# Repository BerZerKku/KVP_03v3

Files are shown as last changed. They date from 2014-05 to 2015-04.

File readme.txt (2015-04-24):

Плата KVP_03v3.
Сделана в OrCAD 16.6.

Предназначена для использования в ОПТИКЕ и АВАНТах К400, РЗСК, Р400М 
сделанными в новом варианте.
Используется совместно с BVP не ранее 04v2, если не нужна цифровая
ретрансляция. И не ранее 04v3 если нужна.

Изменения:
Переделана цивровая ретрансляция. Сделан чистый 422 интерфейс и добавлен
сигнал управления.
Терминаторы 120 и 51Ом изменены на 240Ом.

Основной вариант (Р400М):
отсутствуют: цифровая ретрансляция, выходы ком.ПРД/ПРМ, вход ПУСК.

Вариант Р400:
добавлен выход "Предупреждение"

Вариант К400 (РЗСК):
плата запаивается полностью.

Недостатки:
Резисторы подтяжки стоят на выводах X/Y, что при переключении на 422 убирает
подтяжки с выводов A/B и оставляет вход 422 интерфейса без подтяжки. 
Вообще дуплекс/полудуплекс сделан хреново.
Место резисторов можно поставить предохранители.

!!!
На данный момент входы управления запаиваются только под 24.
Номиналы резисторов для других напряжений см. в РЭ.
!!!

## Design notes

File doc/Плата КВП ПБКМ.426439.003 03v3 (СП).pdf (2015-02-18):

№ | Наименование | Корпус | Кол. | Поз. | Примечание
| | | | | ПБКМ.426439.003

0

Изм | Лист | № докум. | Подп. | Дата
Разраб. | Щеблыкин М.В | | 18.02.15 | Плата КВП 03v3 Спецификация | Лит. | Лист | Листов
Провер. | Вершинин А.С. | | 18.02.15 | | | 1 | 7

### ООО «Прософт-Системы»

Н.контр. | Назаренко А.Н. | 18.02.15
Утв. | Чирков А.Г.
1 | Сборочный чертеж
| ПБКМ.426439.003 rev.0 | 1

ДЕТАЛИ

3 | Плата печатная
| KVP_03v3 | 1

ПРОЧИЕ ИЗДЕЛИЯ

5 | Диод 1N4148WS FAIRCHILD
| (1N4148WS-V VISHAY) | SOD-323 | 2 | VD21,VD24

Конденсаторы

9 | 0805 X7R 50В 0.01мкФ ±10% | 0805 | 4 | C5,C8,C14,C17
11 | 0805 X7R 50В 0.1мкФ ±10% | 0805 | 14 | C1,C3,C4,C6,C9,C10,C12,C13,C15,
| | | | C18,C28,C29,C32,C34
13 | 1206 X7R 50В 0.1мкФ ±10% | 1206 | 2 | C33,C35
15 | 1210 X7R 25В 10мкФ ±10% | 1210 | 4 | C2,C7,C11,C16

Микросхемы

19 | ADM2587EBRWZ 500kB AD | SOIC_20 | 2 | DD2,DD4
21 | SN74LVC1G14DBV(R, T) TI
| (74LVC1G14GV PANASONIC, NXP) | SOT-23_5 | 2 | DD1,DD3
23 | ULN2803ADW TI (ULN2803ADWR
| TI, ULN2803AFWG TOSHIBA) | SOIC_18 | 1 | DD7
27 | Оптрон ACPL-M50L-500E AVAGO | SMD_5 | 2 | AV2,AV3

# ПБКМ.426439.003

Лист

2 Изм | Лист | № докум. | Подп. | Дата
31 | Переключатель SmWDL-02
| DIPTRONICS | SMD_4 | 4 | S1-S4

Разъемы

35 | Разъем 231-576/001-000 WAGO | 16 pins | 2 | X2,X3
37 | Разъем DIN 41612 3*32 64 MR | 64 pins | 1 | X1 | вилка угловая
39 | Разъем PLS-2 | PLS_2 | 2 | X4,X5

Резисторы

43 | 0805 10Ом ±5% | 0805 | 8 | R5,R8-R10,R17,R20-R22
45 | 0805 100Ом ±5% | 0805 | 4 | R3,R4,R15,R16
47 | 0805 470Ом ±5% | 0805 | 4 | R11,R12,R23,R24
49 | 0805 2кОм ±5% | 0805 | 2 | R53,R61
51 | 0805 6.2кОм ±5% | 0805 | 1 | R37
53 | 0805 10кОм ±5% | 0805 | 4 | R1,R2,R13,R14
55 | 1206 240Ом ±5% | 1206 | 4 | R6 R7,R18,R19
58 | 2010 100Ом ±5% | 2010 | 2 | R54,R62
69 | Реле D3212 FX2 24VDC AXICOM
| (G6S-2-24DC OMRON) | 8 pins | 1 | K1

Супрессоры

73 | SM6T6V8CA 6.8В двунаправленный | DO-214AA | 11 | VD1-VD8,VD20,VD23,VD27
75 | SM6T18A 18В однонаправленный | DO-214AA | 2 | VD22,VD25
77 | SM6T30CA 30В двунаправленный | DO-214AA | 1 | VD26
79 | SMBJ300CA 300B двунаправленный | DO-214AA | 1 | VD13
83 | Ферритовая бусина
| BLM31PG601SN1 MURATA | 1206 | 8 | FB1-FB8

| | | | 3 Изм
Лист | № докум. | Подп. | Дата

Переменные данные для

исполнений:

ВАРИАНТ К400

5 | Диод 1N4148WS FAIRCHILD
| (1N4148WS-V VISHAY) | SOD-323 | 1 | VD19

Конденсаторы

9 | 0805 X7R 50В 0.01мкФ ±10% | 0805 | 2 | C23,C26
11 | 0805 X7R 50В 0.1мкФ ±10% | 0805 | 6 | C19,C21,C22,C24,C27,C30
13 | 1206 X7R 50В 0.1мкФ ±10% | 1206 | 1 | C31
15 | 1210 X7R 25В 10мкФ ±10% | 1210 | 2 | C20,C25

Микросхемы

19 | ADM2587EBRWZ 500kB AD | SOIC_20 | 1 | DD6
21 | SN74LVC1G14DBV(R, T) TI
| (74LVC1G14GV PANASONIC, NXP) | SOT-23_5 | 1 | DD5
Оптрон ACPL-M50L-500E AVAGO | SMD_5 | 1 | AV1
31 | Переключатель SmWDL-02
| DIPTRONICS | SMD_4 | 1 | S5

Резисторы

43 | 0805 10Ом ±5% | 0805 | 4 | R29,R32-R34
45 | 0805 100Ом ±5% | 0805 | 3 | R27,R28,R66
47 | 0805 470Ом ±5% | 0805 | 2 | R35,R36
49 | 0805 2кОм ±5% | 0805 | 1 | R44

| | | | 4 Изм
Лист | № докум. | Подп. | Дата
51 | 0805 6.2кОм ±5% | 0805 | 3 | R38-R40
53 | 0805 10кОм ±5% | 0805 | 3 | R25,R26,R65
55 | 1206 240Ом ±5% | 1206 | 2 | R30,31
58 | 2010 100Ом ±5% | 2010 | 1 | R46
69 | Реле D3212 FX2 24VDC AXICOM
| (G6S-2-24DC OMRON) | 8 pins | 3 | K2-K4

Супрессоры

73 | SM6T6V8CA 6.8В двунаправленный | DO-214AA | 5 | VD9-VD12,VD17
75 | SM6T18A 18В однонаправленный | DO-214AA | 1 | VD18
79 | SMBJ300CA 300B двунаправленный | DO-214AA | 3 | VD14-VD16
83 | Ферритовая бусина
| BLM31PG601SN1 MURATA | 1206 | 4 | FB9-FB12

ВАРИАНТ Р400

51 | Резистор 0805 6.2кОм ±5% | 0805 | 1 | R38
69 | Реле D3212 FX2 24VDC AXICOM
| (G6S-2-24DC OMRON) | 8 pins | 1 | K2
79 | SMBJ300CA 300B двунаправленный | DO-214AA | 1 | VD14

| | | | 5 Изм
Лист | № докум. | Подп. | Дата

ВАРИАНТ УПР_Р400_24В

59 | Резистор 2010 470Ом ±5% | 2010 | 4 | R49,R56,R57,R64
63 | Резистор 2010 1.2кОм ±5% | 2010 | 2 | R52,R60
64 | Резистор 2010 1.8кОм ±5% | 2010 | 2 | R51,R59
65 | Резистор SQM 5.1кОм 5Вт ±5% | 2 pins | 4 | R50,R55,R58,R63 | Не устанавл.

ВАРИАНТ УПР_Р400_110В

59 | Резистор 2010 470Ом ±5% | 2010 | 2 | R56,R64
60 | Резистор 2010 | 2010 | 2 | R49,R57 | Не устанавл.
63 | Резистор 2010 1.2кОм ±5% | 2010 | 4 | R51,R52,R59,R60
65 | Резистор SQM 5.1кОм 5Вт ±5% | 2 pins | 2 | R50,R58
66 | Резистор SQM | 2 pins | 2 | R55,R63 | Не устанавл.

ВАРИАНТ УПР_Р400_220В

59 | Резистор 2010 470Ом ±5% | 2010 | 4 | R49,R56,R57,R64 | Не устанавл.
61 | Резистор 2010 1кОм ±5% | 2010 | 2 | R51,R59
62 | Резистор 2010 1.1кОм ±5% | 2010 | 2 | R52,R60
65 | Резистор SQM 5.1кОм 5Вт ±5% | 2 pins | 4 | R50,R55,R58,R63

| | | | 6 Изм
Лист | № докум. | Подп. | Дата

ВАРИАНТ УПР_ К400_24В

59 | Резистор 2010 470Ом ±5% | 2010 | 6 | R41,R48,R49,R56,R57,R64
63 | Резистор 2010 1.2кОм ±5% | 2010 | 3 | R43,R52,R60
64 | Резистор 2010 1.8кОм ±5% | 2010 | 3 | R45,R51,R59
65 | Резистор SQM 5.1кОм 5Вт ±5% | 2 pins | 6 | R42,R47,R50,R55,R58,R63 | Не устанавл.

ВАРИАНТ УПР_К400_110В

59 | Резистор 2010 470Ом ±5% | 2010 | 3 | R48,R56,R64
60 | Резистор 2010 | 2010 | 3 | R41,R49,R57 | Не устанавл.
63 | Резистор 2010 1.2кОм ±5% | 2010 | 6 | R43,R45,R51,R52,R59,R60
65 | Резистор SQM 5.1кОм 5Вт ±5% | 2 pins | 3 | R42,R50,R58
66 | Резистор SQM | 2 pins | 3 | R47,R55,R63 | Не устанавл.

ВАРИАНТ УПР_К400_220В

59 | Резистор 2010 470Ом ±5% | 2010 | 6 | R41,R48,R49,R56,R57,R64 | Не устанавл.
61 | Резистор 2010 1кОм ±5% | 2010 | 3 | R45,R51,R59
62 | Резистор 2010 1.1кОм ±5% | 2010 | 3 | R43,R52,R60
65 | Резистор SQM 5.1кОм 5Вт ±5% | 2 pins | 6 | R42,R47,R50,R55,R58,R63

| | | | 7 Изм
Лист | № докум. | Подп. | Дата

### Лист регистрции изменений СП

№ ревизии | № замененных (измененных) страниц | Дата ревизии | Краткое содержание и причина внесения изменений | Примечание
0 | вновь | 18.02.15 | На замену «АВАНТ КВП v3.3».

Исполнения:
Основное – для Р400м;
Р400 – для Р400;
К400 – для К400 и РЗСК.
ОБЯЗАТЕЛЬНО для каждого исполнения указать вариант исполнения входов управления, в зависимости от необходимого рабочего напряжения (24В, 110В или 220В):
Для Основного и Р400 – УПР_Р400_24В, УПР_Р400_110В или УПР_Р400_220В;
Для К400 – УПР_К400_24В,УПР_К400_110В или УПР_К400_220В.
Например:
К400 + УПР_К400_220В – для К400 с рабочим напряжением входов ТМ,СБРОС,ПУСК 220 вольт. Р400 + УПР_Р400_110В – для Р400 с рабочим напряжением входов ТМ, СБРОС 110 вольт. УПР_Р400_24В – для Р400м с рабочим напряжением входов ТМ, СБРОС 24 вольта.

### Лист регистрции изменений СБ

№ ревизии | № замененных (измененных) страниц | Дата ревизии | Краткое содержание и причина внесения изменений | Примечание
0 | вновь | 18.02.15 | На замену «АВАНТ КВП v3.3».

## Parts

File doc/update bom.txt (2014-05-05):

Изменения в спецификации по сравнению с платой КВП_03v2.

ВАРИАНТ ОСНОВНОЙ:
поз.55 резистор 1206 51  - заменена на 1206 240 4 шт (добавлены R6,R7,R18,R19)
поз.57 резистор 1206 120 - убрана

ВАРИАНТ К400:
поз.31 SmWDL-02 1 шт (убран S6)
поз.45 резистор 0805 100 3 шт (R27,R28,добавлен R66)
поз.53 резистор 0805 10к 3 шт (добавлены R25,R26,R65)
поз.55 резистор 1206 51  - заменена на 1206 240 2 шт (добавлены R30, R31)
поз.57 резистор 1206 120 - убрана

Позиции перенесенные в вариантное исполнение "УПР хххх ххх":
поз.59 резистор 2010 470 
поз.61 резистор 2010 1к
поз.62 резистор 2010 1.1к
поз.63 резистор 2010 1.2к
поз.64 резистор 2010 1.8к
поз.65 резистор SQM  5.1к

На данный момент надо 4 платы: К400 + УПР К400 220В

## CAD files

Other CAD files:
doc/Плата КВП ПБКМ.426439.003 03v3 (СБ).dwg
pcb/h320.psm

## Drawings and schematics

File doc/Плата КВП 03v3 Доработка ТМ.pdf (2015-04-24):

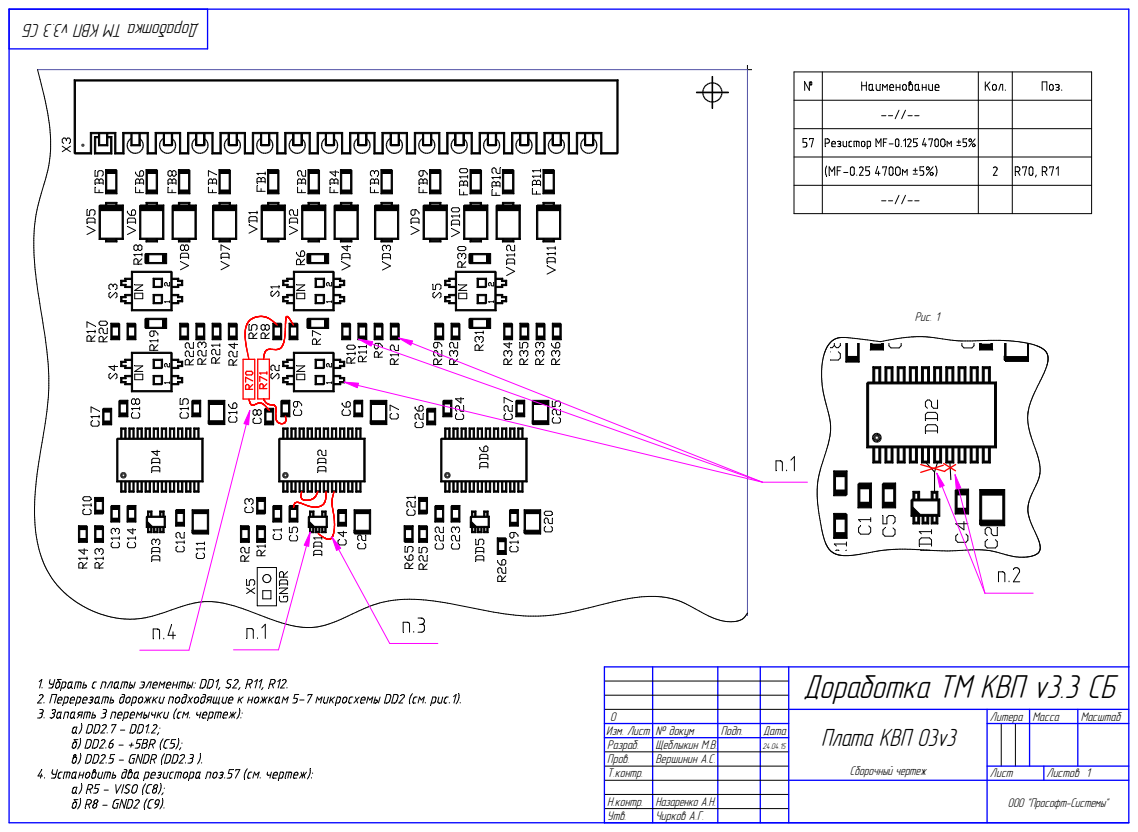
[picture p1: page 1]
Ðèñ. 1; Ëèñòîâ 1; Ìàññà; Ìàñøòàá; Ïîäï.; Äàòà; Óòâ.; Í.êîíòð.; Ò.êîíòð.; Ïðîâ.; Ðàçðàá.; Èçì. Ëèñò; ×èðêîâ À.Ã.; Íàçàðåíêî À.Í.; Âåðøèíèí À.Ñ.; Ùåáëûêèí Ì.Â.; № äîêóì; Ëèñò; Ëèòåðà; Ïëàòà ÊÂÏ 03v3

Äîðàáîòêà ÒÌ ÊÂÏ v3.3 ÑÁ

Ñáîðî÷íûé ÷åðòåæ

ÎÎÎ "Ïðîñîôò-Ñèñòåìû"

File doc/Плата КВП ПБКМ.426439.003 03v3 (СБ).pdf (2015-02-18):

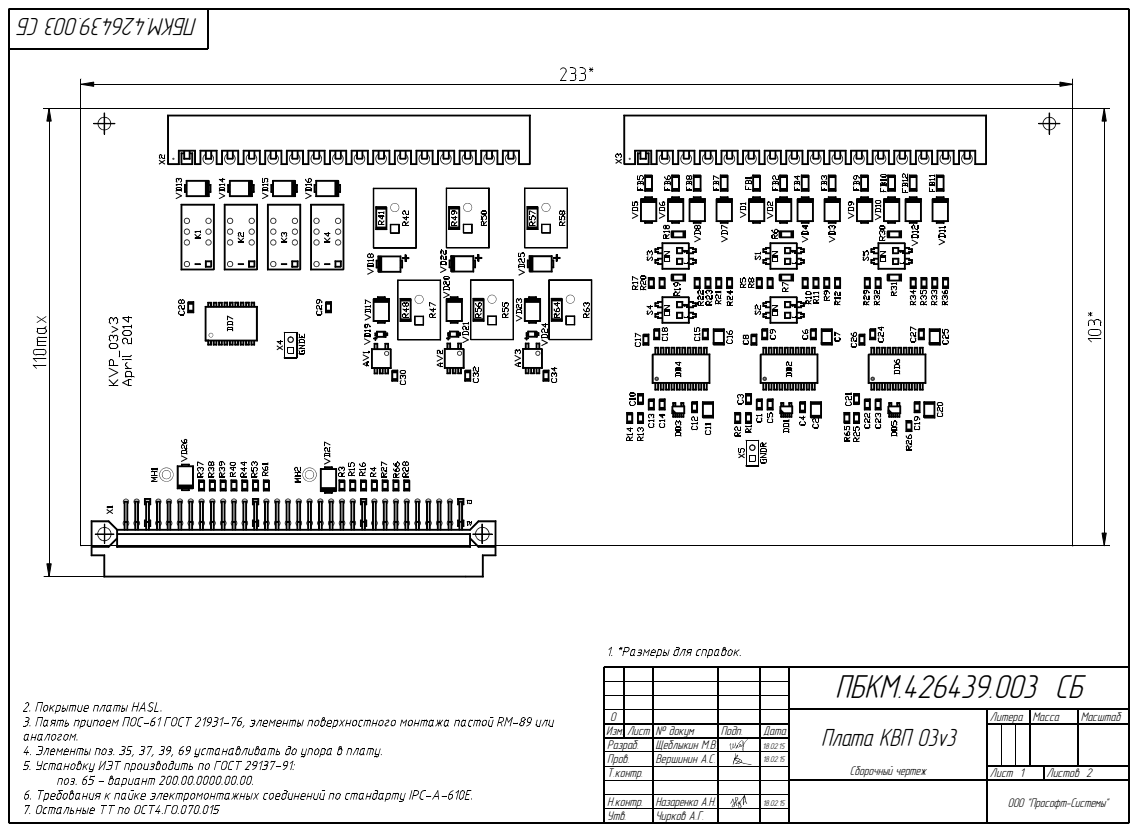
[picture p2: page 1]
Ëèñòîâ 2; Ìàññà; Ìàñøòàá; Ïîäï.; Äàòà; Óòâ.; Í.êîíòð.; Ò.êîíòð.; Ïðîâ.; Ðàçðàá.; Èçì. Ëèñò; ×èðêîâ À.Ã.; Íàçàðåíêî À.Í.; Âåðøèíèí À.Ñ.; Ùåáëûêèí Ì.Â.; № äîêóì; Ëèñò 1; Ëèòåðà; ÏÁÊÌ.426439.003 ÑÁ; Ïëàòà ÊÂÏ 03v3

Ñáîðî÷íûé ÷åðòåæ

ÎÎÎ "Ïðîñîôò-Ñèñòåìû"

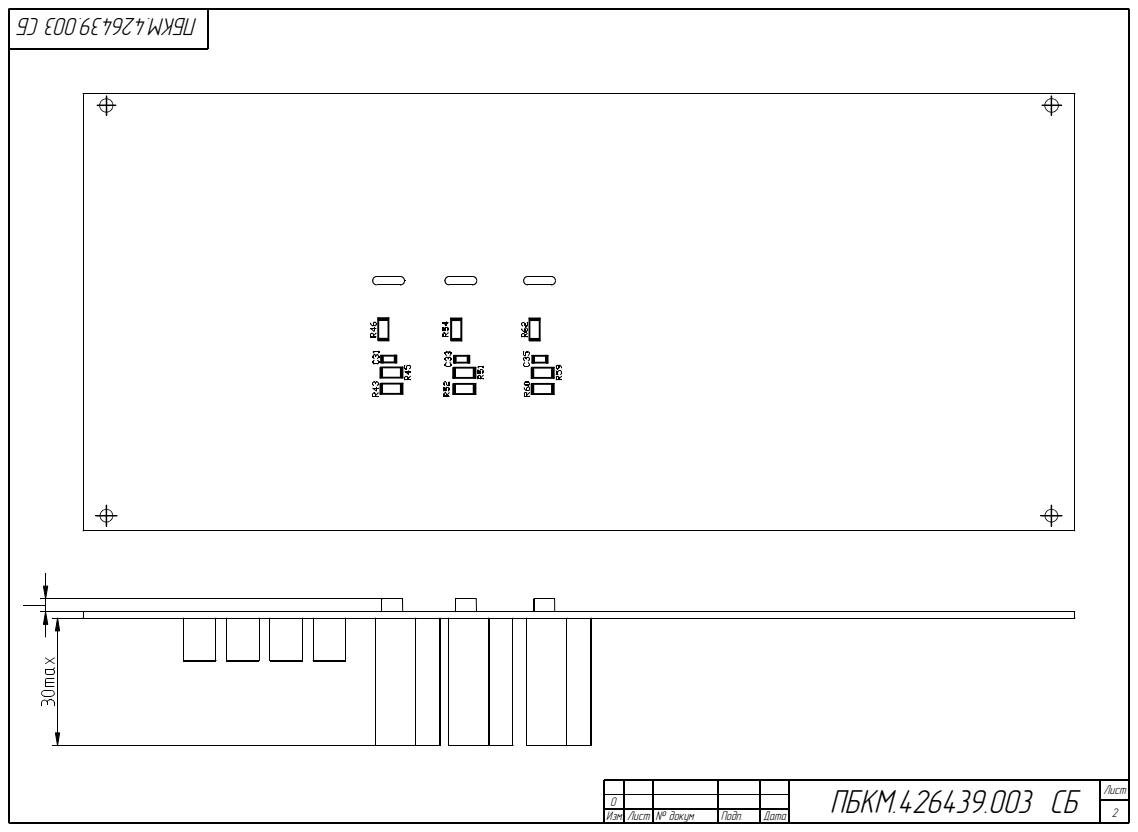
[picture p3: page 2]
Ëèñò; Èçì. Ëèñò № äîêóì; Ïîäï.; Äàòà; ÏÁÊÌ.426439.003 ÑÁ

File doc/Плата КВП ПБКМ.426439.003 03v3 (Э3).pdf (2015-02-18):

# X1-1DIN⁻³²x2

D1

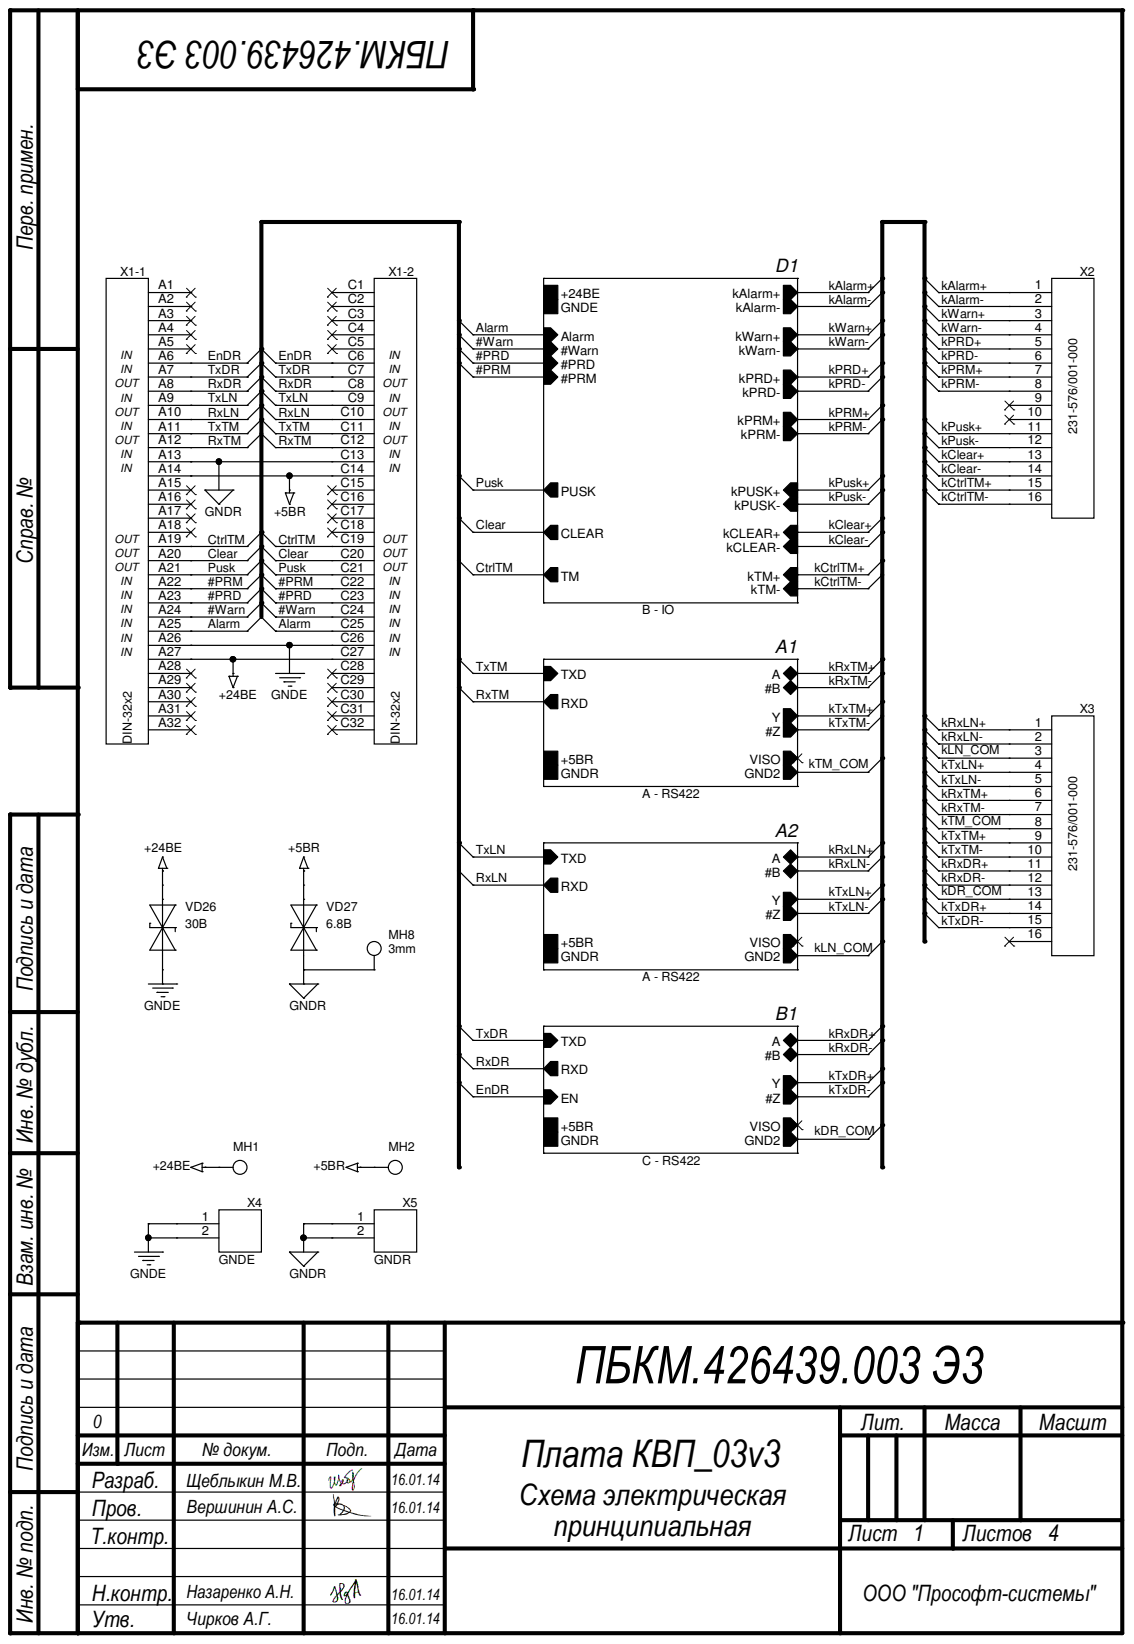
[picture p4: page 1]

Инв. № подп. Подпись и дата Взам. инв. № Инв. № дубл. Подпись и дата

ПБКМ.426439.003 Э3

0 | | | | | Плата КВП_03v3 Схема электрическая принципиальная | Лит. | Масса | Масшт
Изм. | Лист | № докум. | Подп. | Дата
Разраб. | | Щеблыкин М.В. | | 16.01.14
Пров. | Вершинин А.С. | | 16.01.14
Т.контр. | | | | | Лист 1 | Листов 4

Н.контр. | Назаренко А.Н. | 16.01.14
Утв. | Чирков А.Г. | 16.01.14

ООО "Прософт-системы"

# A - RS485/RS422

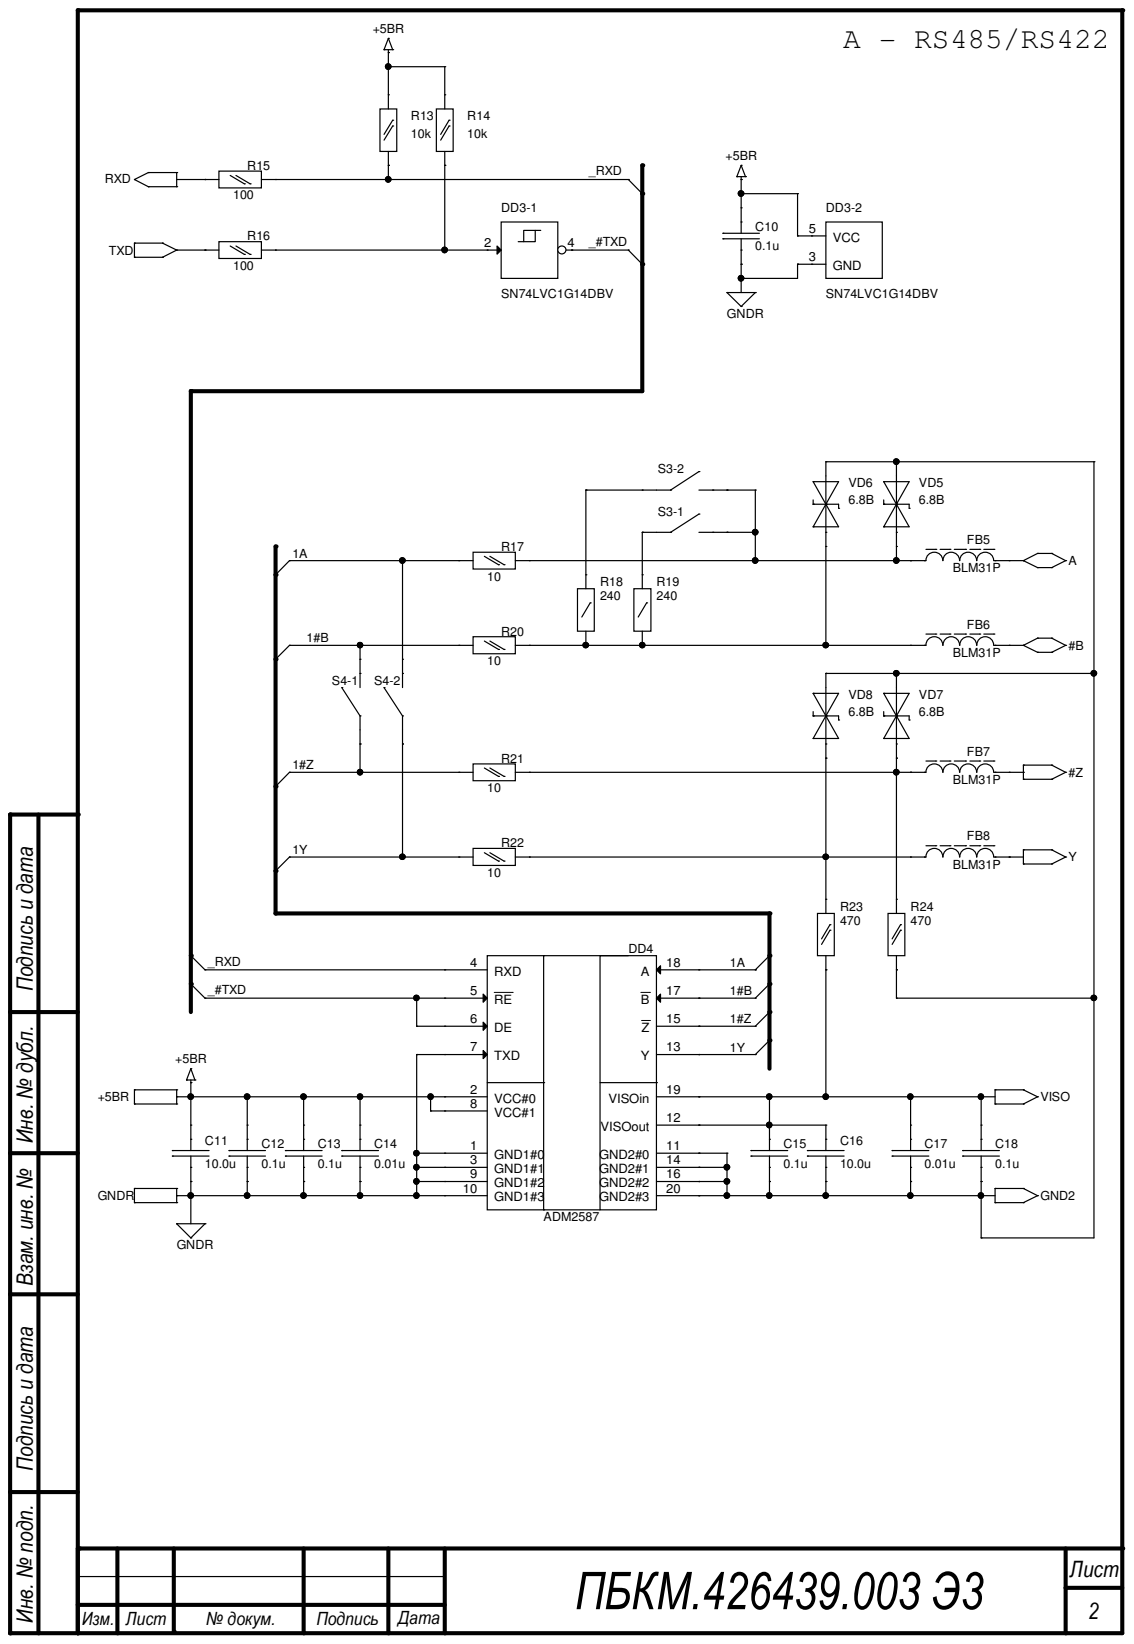
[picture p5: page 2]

Инв. № подп. Подпись и дата Взам. инв. № Инв. № дубл. Подпись и дата

# A - RS485/RS422

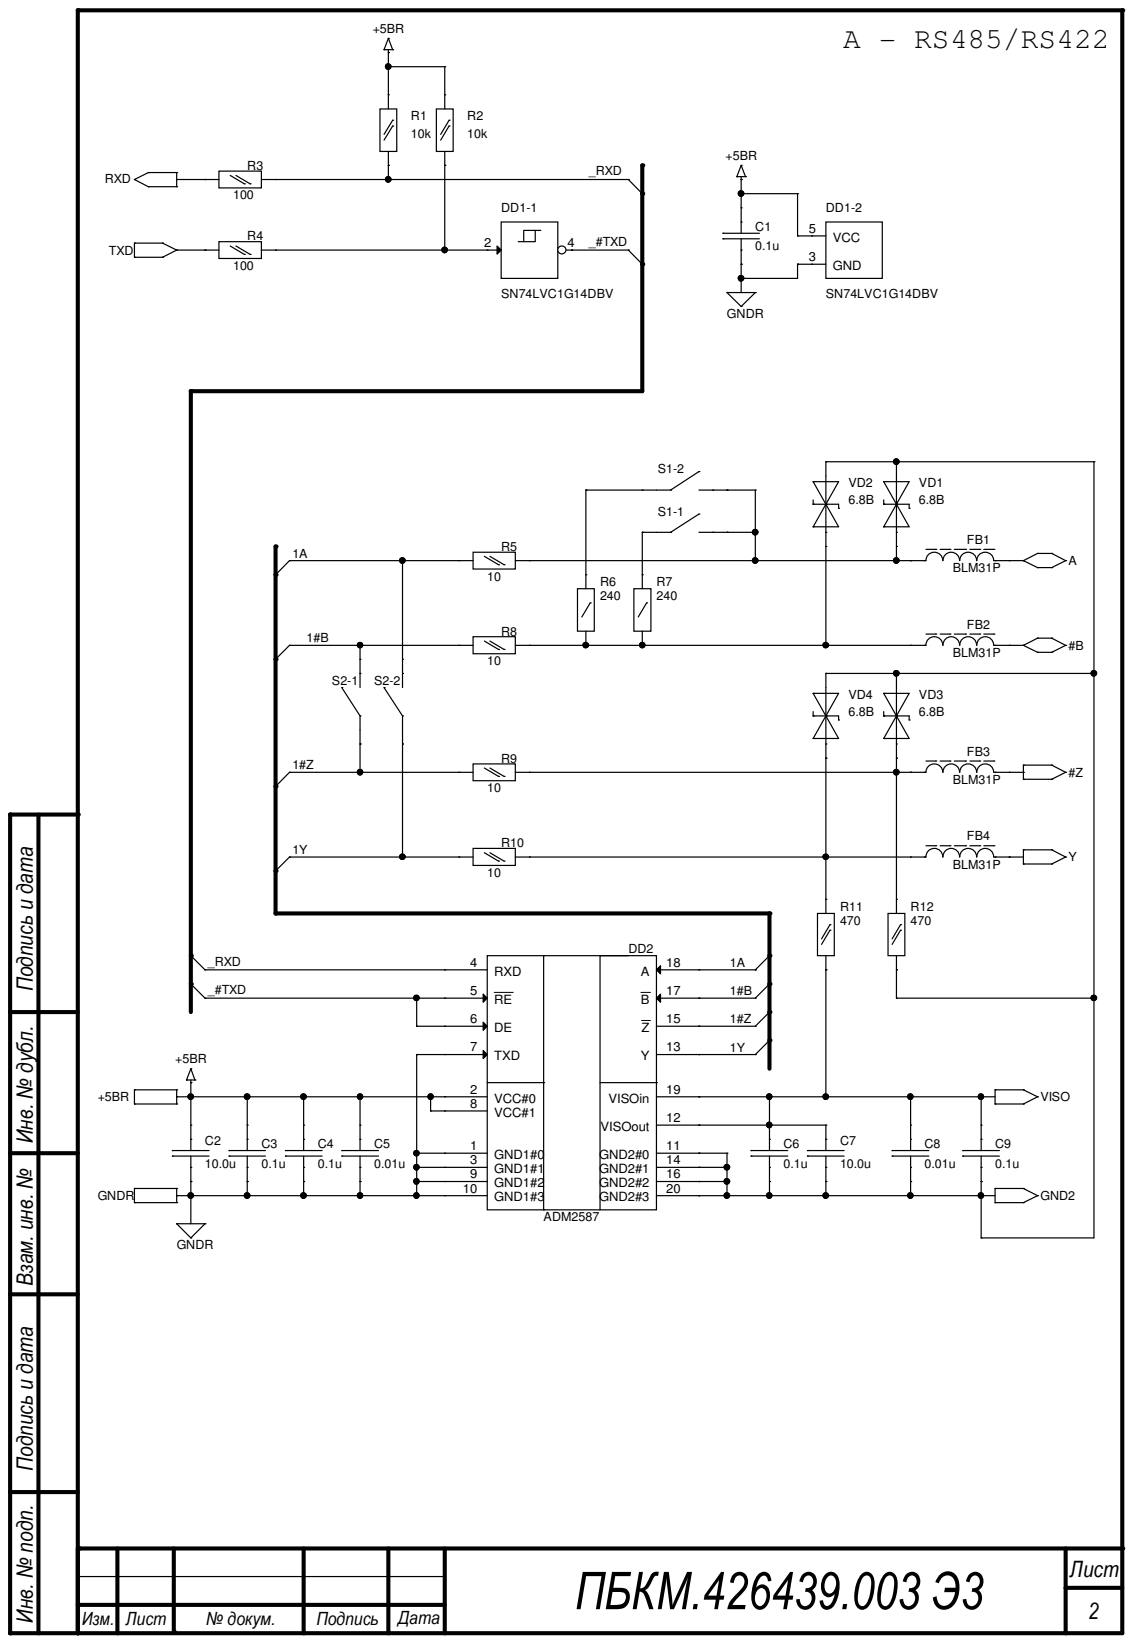
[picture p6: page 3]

Инв. № подп. Подпись и дата Взам. инв. № Инв. № дубл. Подпись и дата

# B - I/O

K

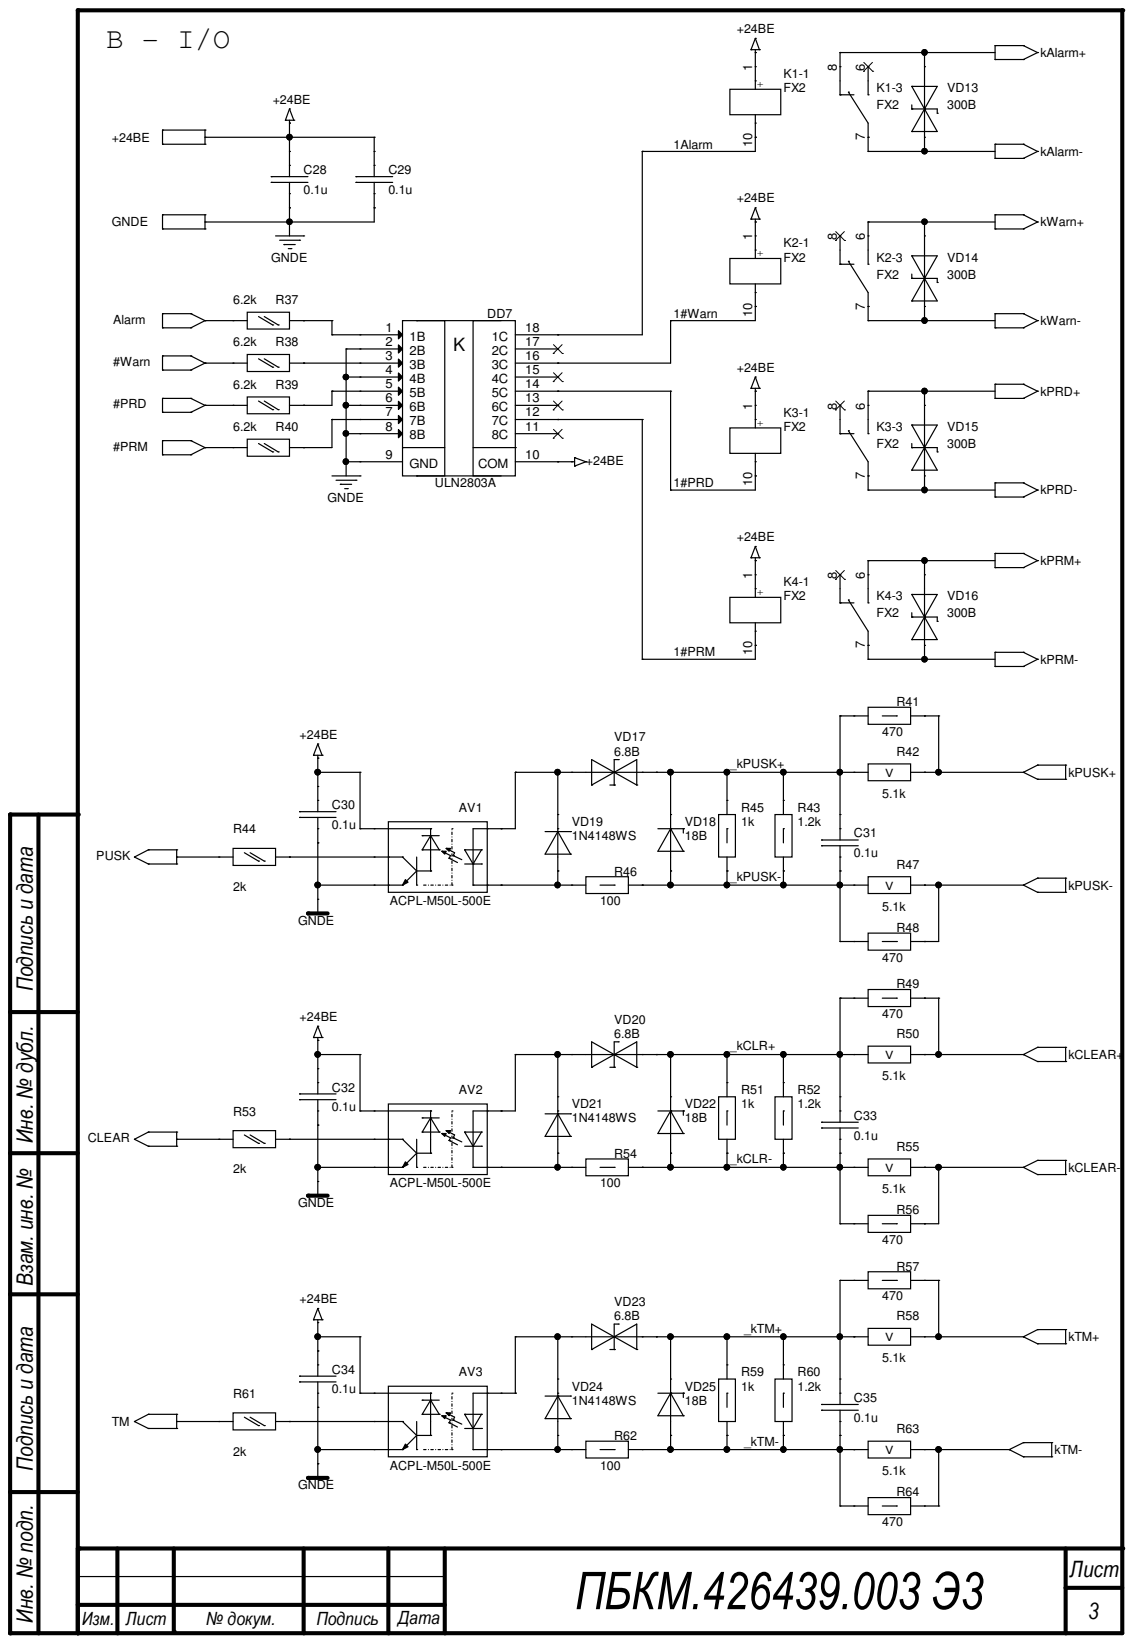
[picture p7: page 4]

Инв. № подп. Подпись и дата Взам. инв. № Инв. № дубл. Подпись и дата

# C - RS422

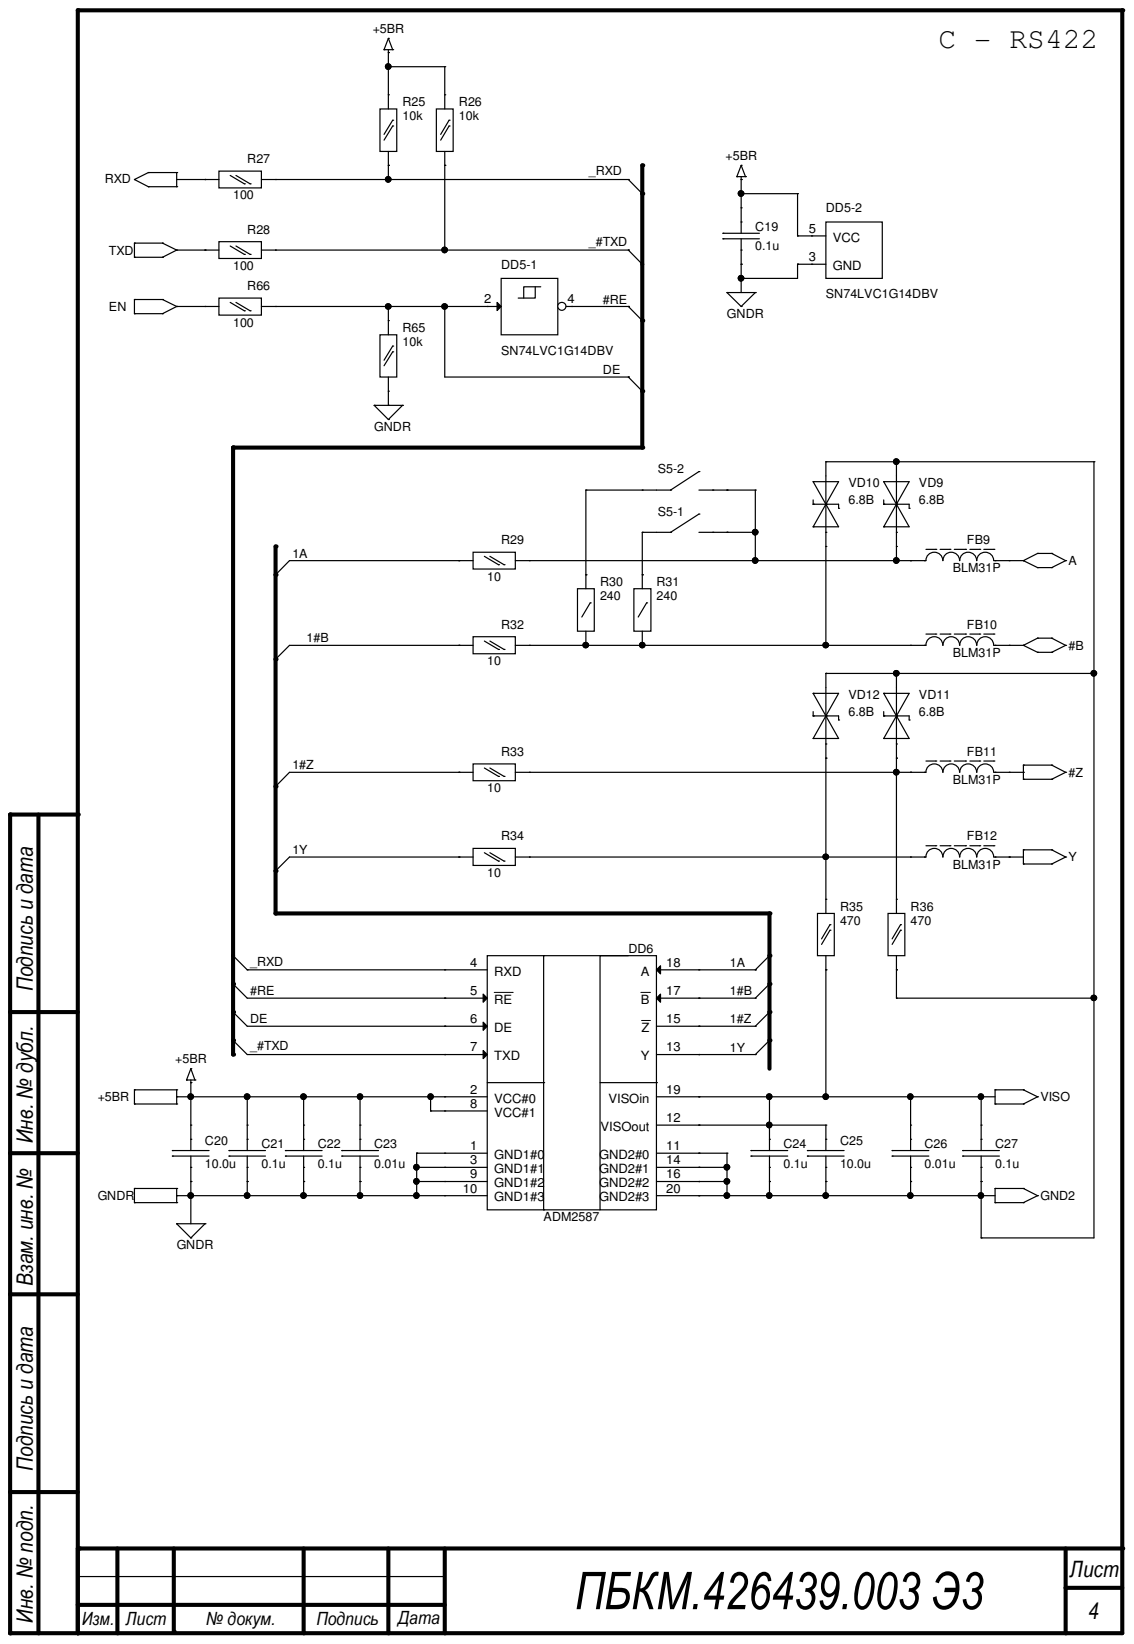
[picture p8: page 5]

Инв. № подп. Подпись и дата Взам. инв. № Инв. № дубл. Подпись и дата

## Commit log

2014-04-02 Вновь.
    [KVP_03V3.DSN, kvp_03v3.brd]
2014-04-03 Закончена разводка.
    [KVP_03V3.DSN, kvp_03v3.brd]
2014-04-29 Небольшие правки шелкографии/сборки.
    [KVP_03V3.DSN, kvp_03v3.brd]
2014-05-05 Немного почищена разводка. Подготовлены файлы к заказу.
    [art_param.txt, h320.psm, kvp_03v3.brd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]
2014-05-05 Добавлена СП.
    [KVP_03V3.DSN]
2014-05-05 Подправлено оформление СП.
2014-05-20 Добавлен сборочник и общая документация.
    [Плата КВП KVP_03v3 (СБ).dwg]
2014-07-29 Небольшие коррекции оформления, для подготовки схемы к печати. Добавлен Э3.
    [KVP_03V3.DSN]
2015-02-18 Изменены децимальные номера.
    [KVP_03V3.DSN, Плата КВП KVP_03v3 (СБ).dwg, Плата КВП ПБКМ.426439.003 03v3 (СБ).dwg]
2015-04-24 Добавлена доработка ТМ до полного дуплекса (422 интерфейс).
    [Плата КВП ПБКМ.426439.003 03v3 (СБ).dwg]
